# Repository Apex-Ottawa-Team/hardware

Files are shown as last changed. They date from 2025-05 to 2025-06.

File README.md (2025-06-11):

The Ottawa Skybound Logo

# Apex Hardware

## Overview

This repository contains the hardware design files for Ottawa Skybound's weather ballon for [Apex](https://apex.hackclub.com). The repository contains of multiple PCB modules designed in KiCad. The system includes a motherboard, wireless communication module, and various sensor interfaces.

## Boards

LoRa Module: Wireless communication module using LoRa technology. Designed by Adam Turaj

Motherboard: Main control board for the Apex system. Designed by Adam Turaj

Sensor Board: A board containing an IMU and temperature reader. Designed by Joshua Gallinger

Strain ADC: Analog-to-digital converter board for strain measurements. Designed by Adam Turaj

Archive/RF Module: Previous design iteration of the LoRa board. Designed by Adam Turaj

Gas Sensor: Collects data on TVOC concentrations in the air. Designed by Aryan Zafer

Ground RF: Board used to communicate and receive data from the weather balloon. Designed by Aryan Zafer

## Development Requirements

KiCad 9.0 or newer

## License

This project is licensed under the GNU GENERAL PUBLIC LICENSE. The license can be found [here](https://github.com/Apex-Ottawa-Team/hardware/blob/main/LICENSE).

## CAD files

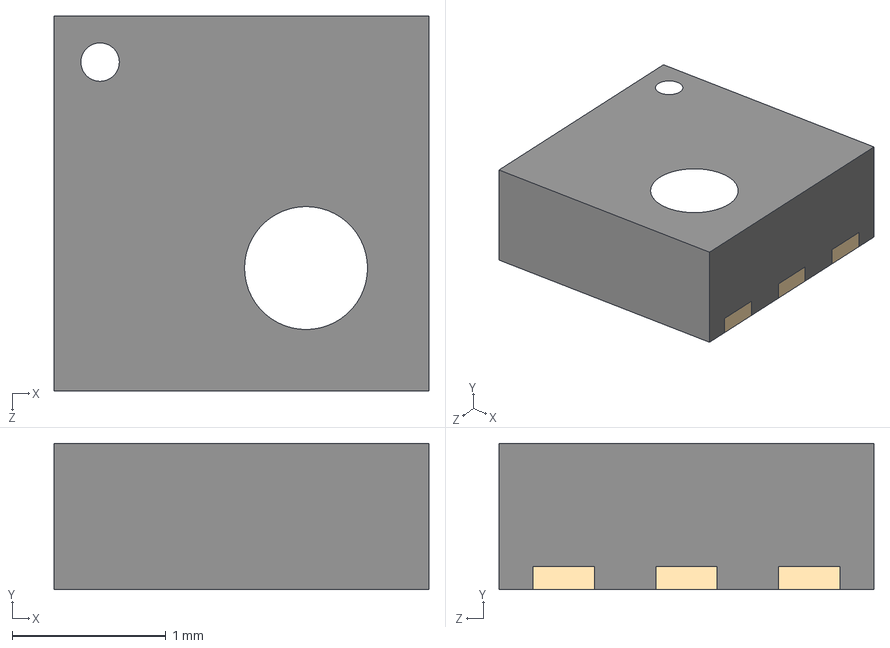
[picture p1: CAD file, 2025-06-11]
Gas Sensor/SGP40-D-R4.step
2.44 x 0.95 x 2.44 mm

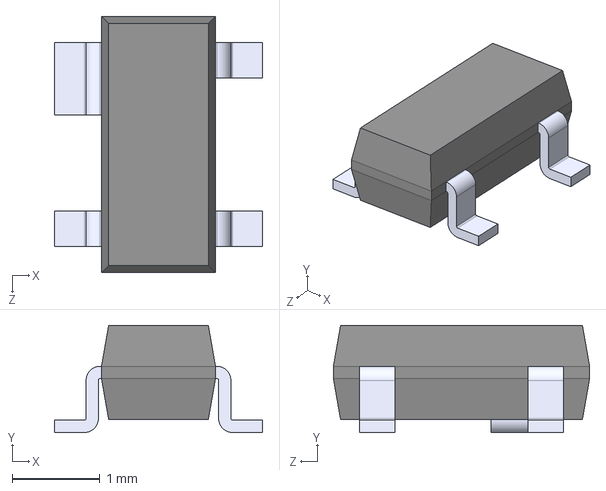
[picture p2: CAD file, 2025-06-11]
Ground RF/3d/SP0503BAHTG.step
2.37 x 1.22 x 2.92 mm

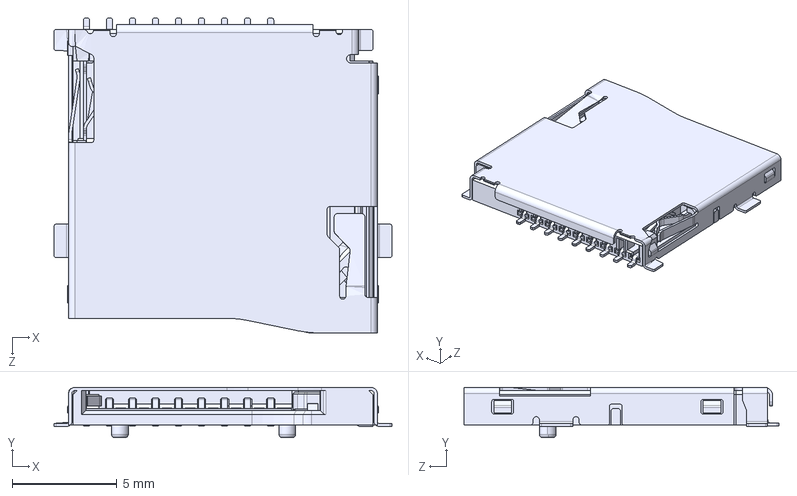
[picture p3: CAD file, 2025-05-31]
Motherboard/STEP/Same_Sky_MSD-1-A.step
16.1 x 2.40 x 15.0 mm

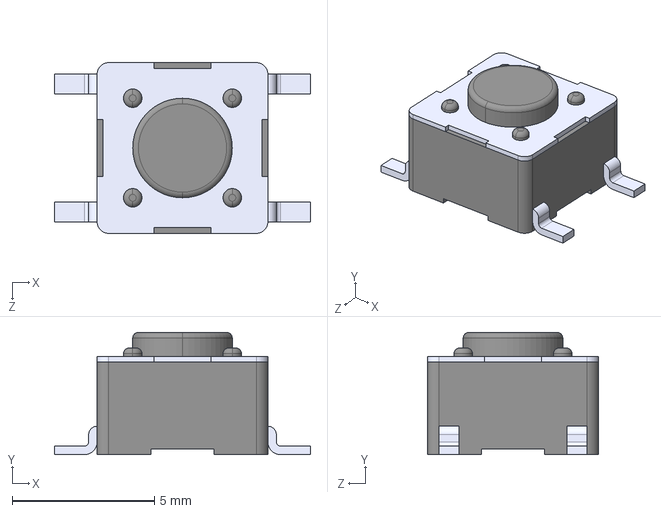
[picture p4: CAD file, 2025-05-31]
Motherboard/STEP/PTS645SK43SMTR92 LFS.STEP
9.00 x 4.30 x 6.00 mm

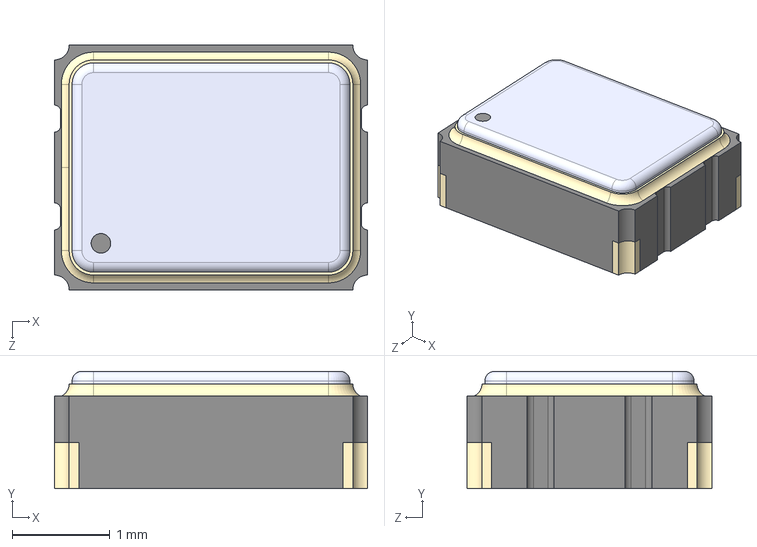
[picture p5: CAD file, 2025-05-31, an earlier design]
Archive/RF Module/Models/TX32-M010S-32.000-X-R.STEP
3.20 x 1.20 x 2.50 mm

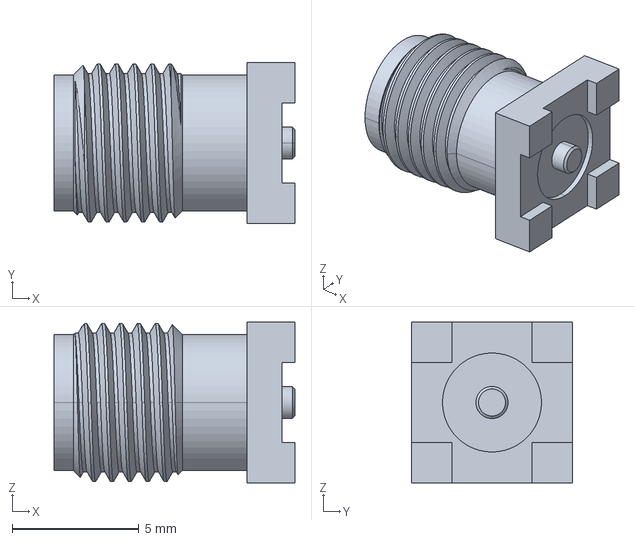
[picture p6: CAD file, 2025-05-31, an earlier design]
Archive/RF Module/Models/732511353.stp
9.53 x 6.35 x 6.35 mm

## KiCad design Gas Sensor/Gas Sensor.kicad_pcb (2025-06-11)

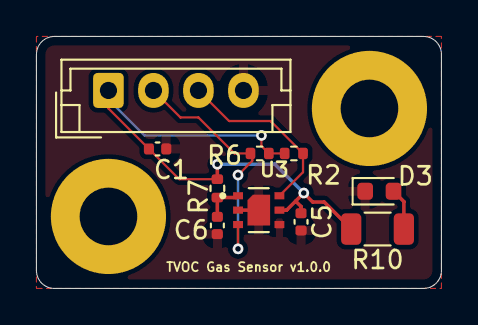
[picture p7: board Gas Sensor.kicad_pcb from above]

Board: 2 copper layers, 22.5 x 14.0 mm, 10 parts (0 on the bottom side), 6 nets.

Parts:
C1: 10uF; C_0402_1005Metric
C5, C6: 0.1uF; C_0402_1005Metric
D3: LED; LED_0603_1608Metric
J1: Conn_Sensors; JST_EH_B4B-EH-A_1x04_P2.50mm_Vertical
R2, R6: 10k; R_0402_1005Metric
R7: 4.7; R_0402_1005Metric
R10: 220; R_1206_3216Metric
U3: SGP40-D-R4; XCDR_SGP40-D-R4

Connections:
+3.3V: C1.1, C5.1, J1.1 (VCC), R2.1, R6.2, R7.2, R10.1, U3.5 (VDDH)
GND: C1.2, C5.2, C6.2, D3.1 (K), J1.4 (GND), U3.2 (VSS), U3.4 (N/A), U3.7 (EXP)
unnamed: D3.2 (A), R10.2
unnamed: C6.1, R7.1, U3.1 (VDD)
SCL: J1.3 (SNS_SCL), R2.2, U3.6 (SCL)
SDA: J1.2 (SNS_SDA), R6.1, U3.3 (SDA)

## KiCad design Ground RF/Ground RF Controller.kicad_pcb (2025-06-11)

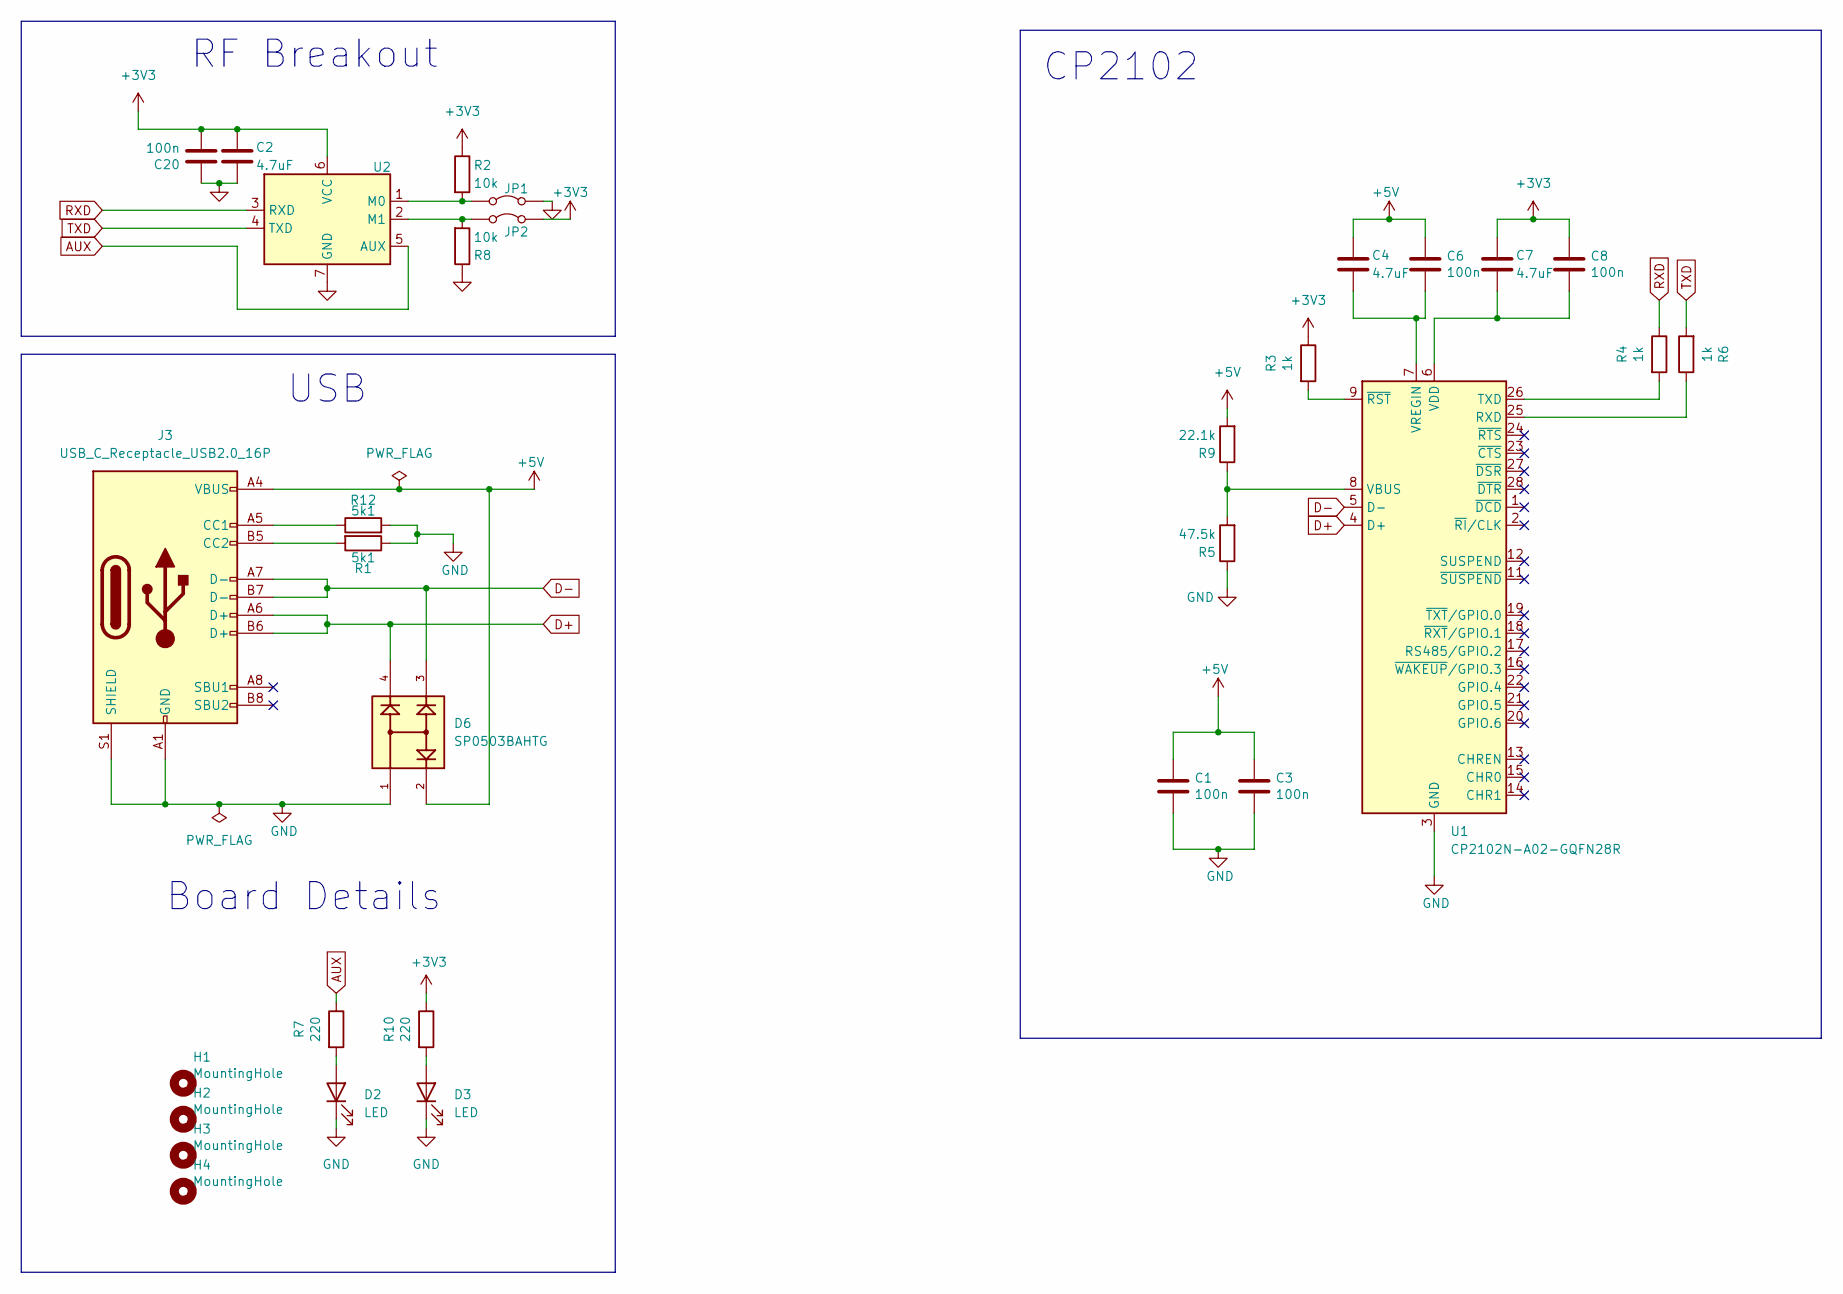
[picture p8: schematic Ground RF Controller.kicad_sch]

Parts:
C1, C3, C6, C8, C20: 100n; C_0402_1005Metric; MPN GRM152R61A104KE19D
C2, C4, C7: 4.7uF; C_0402_1005Metric; MPN GRM155R60J475ME47D
D2, D3: LED; LED_0603_1608Metric; MPN RC0603FR-075K1L
D6: SP0503BAHTG; SOT143; PARTREV N/A
H1, H2, H3, H4: MountingHole; MountingHole_2.7mm_M2.5
J3: USB_C_Receptacle_USB2.0_16P; USB_C_Receptacle_GCT_USB4105-xx-A_16P_TopMnt_Horizontal; MPN USB4105-GF-A-120
JP1, JP2: Jumper_2_Bridged; SolderJumper-2_P1.3mm_Open_RoundedPad1.0x1.5mm
R1, R12: 5k1; R_0603_1608Metric; MPN RC0603FR-075K1L
R2, R8: 10k; R_0402_1005Metric; MPN RC0402JR-0710KL
R3, R4, R6: 1k; R_0805_2012Metric; MPN RC0805JR-071KL
R5: 47.5k; R_0402_1005Metric; MPN CRCW040247K5FKEDC
R7, R10: 220; R_1206_3216Metric; MPN RC1206JR-10220RL
R9: 22.1k; R_0402_1005Metric; MPN CRCW040222K1FKEDC
U1: CP2102N-A02-GQFN28R; QFN-28-1EP_5x5mm_P0.5mm_EP3.35x3.35mm; MPN CP2102N-A02-GQFN28R
U2: EBYTE-E220-900T22D

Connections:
+3V3: C2.1, C7.1, C8.1, C20.2, JP2.2 (B), R2.1, R3.1, R10.1, U2.6 (VCC)
+5V: C1.1, C3.1, C4.1, C6.1, D6.2, J3.A4 (VBUS), J3.A9 (VBUS), J3.B4 (VBUS), J3.B9 (VBUS), R9.2
AUX: R7.1, U2.5 (AUX)
D+: D6.4, J3.A6 (D+), J3.B6 (D+), U1.4 (D+)
D-: D6.3, J3.A7 (D-), J3.B7 (D-), U1.5 (D-)
GND: C1.2, C2.2, C3.2, C20.1, D2.1 (K), D3.1 (K), D6.1, J3.A1 (GND), J3.A12 (GND), J3.B1 (GND), J3.B12 (GND), J3.S1 (SHIELD), JP1.2 (B), R1.1, R5.1, R8.1, R12.2, U1.3 (GND), U1.29 (GND), U2.7 (GND)
unnamed: D2.2 (A), R7.2
unnamed: D3.2 (A), R10.2
unnamed: J3.A5 (CC1), R12.1
unnamed: J3.B5 (CC2), R1.2
unnamed: JP1.1 (A), R2.2, U2.1 (M0)
unnamed: JP2.1 (A), R8.2, U2.2 (M1)
unnamed: R6.1, U1.25 (RXD)
unnamed: R4.2, U1.26 (TXD)
unnamed: R5.2, R9.1, U1.8 (VBUS)
unnamed: C7.2, C8.2, U1.6 (VDD)
unnamed: C4.2, C6.2, U1.7 (VREGIN)
unnamed: R3.2, U1.9 (~RST)
RXD: R4.1, U2.3 (RXD)
TXD: R6.2, U2.4 (TXD)

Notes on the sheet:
USB
CP2102
RF Breakout
Board Details

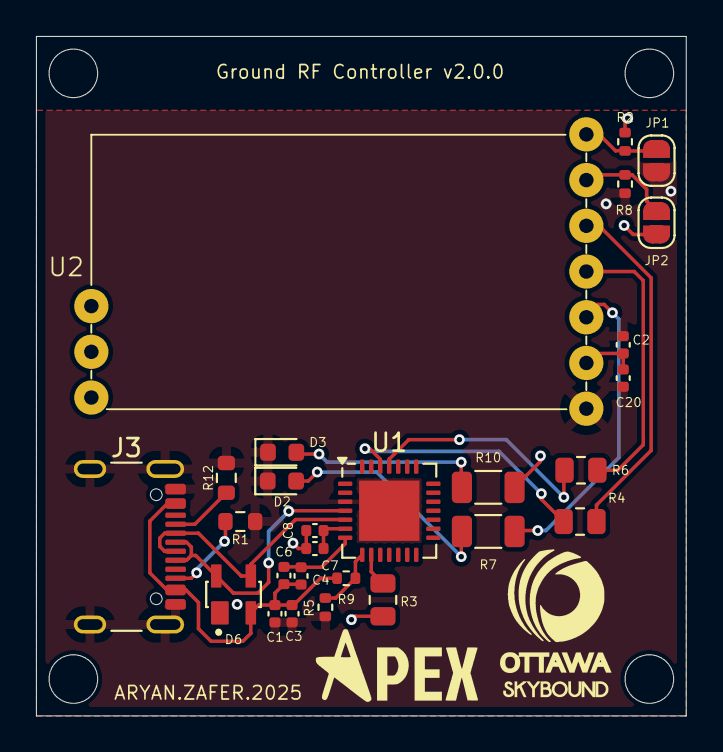
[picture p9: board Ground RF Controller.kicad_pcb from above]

Board: 4 copper layers, 36.1 x 37.8 mm, 31 parts (0 on the bottom side), 20 nets.

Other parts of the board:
H3#2, H3#3, H3#4: MountingHole; MountingHole_2.7mm_M2.5

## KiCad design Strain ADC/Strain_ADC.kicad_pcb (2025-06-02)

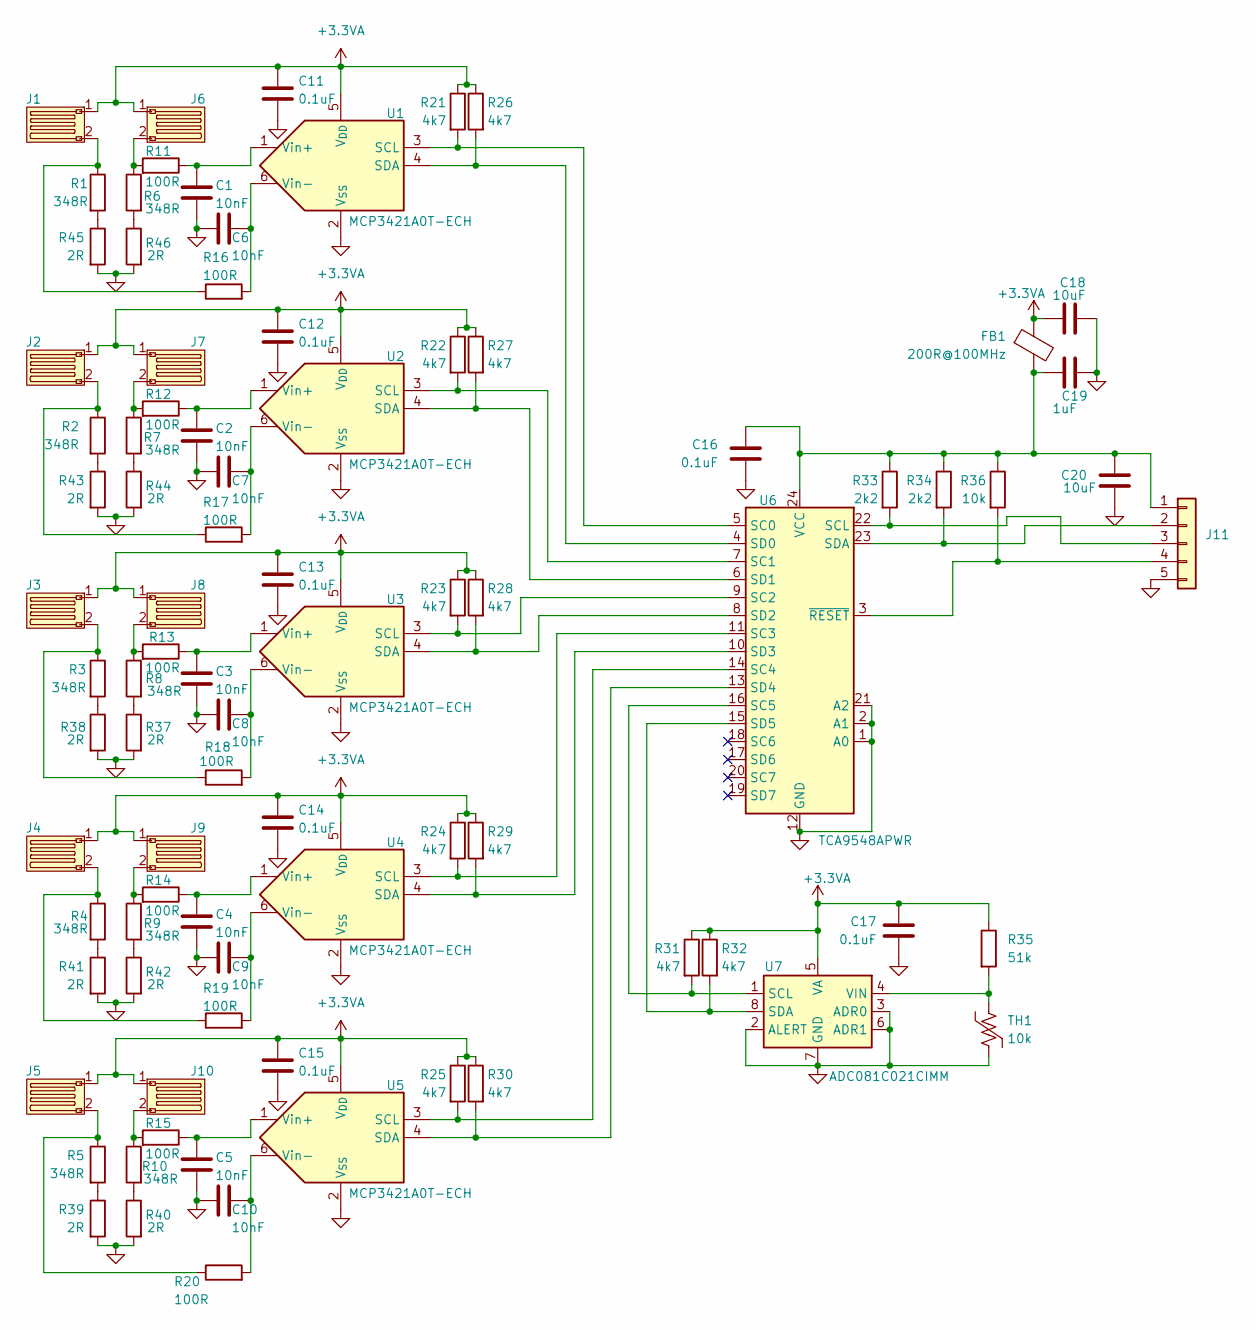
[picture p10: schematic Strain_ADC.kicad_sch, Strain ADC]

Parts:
C1, C2, C3, C4, C5, C6, C7, C8, C9, C10: 10nF; C_0402_1005Metric; Part Number GRM155R71C103KA01D
C11, C12, C13, C14, C15, C16, C17: 0.1uF; C_0402_1005Metric; Part Number CL05B104KP5NNNC
C18, C20: 10uF; C_0402_1005Metric; Part Number CL05A106MQ5NUNC
C19: 1uF; C_0402_1005Metric; Part Number GRM155R70J105KA12D
FB1: 200R@100MHz; L_0805_2012Metric; Part Number BLM21PG221SN1
J1, J2, J3, J4, J5, J6, J7, J8, J9, J10: R_0805_2012Metric
J11: Conn_01x05; JST_XH_B5B-XH-A_1x05_P2.50mm_Vertical; Part Number B5B-XH-A
R1, R2, R3, R4, R5, R6, R7, R8, R9, R10: 348R; R_0402_1005Metric; Part Number ERA-2AEB3480X
R11, R12, R13, R14, R15, R16, R17, R18, R19, R20: 100R; R_0402_1005Metric; Part Number CRCW0402100RFKEDC
R21, R22, R23, R24, R25, R26, R27, R28, R29, R30, R31, R32: 4k7; R_0402_1005Metric; Part Number RC0402FR-074K7L
R33, R34: 2k2; R_0402_1005Metric; Part Number RC0402FR-072K2L
R35: 51k; R_0402_1005Metric; Part Number ERJ-2RKF5102X
R36: 10k; R_0402_1005Metric; Part Number RC0402JR-0710KL
R37, R38, R39, R40, R41, R42, R43, R44, R45, R46: 2R; R_0603_1608Metric; Part Number RT0603BRE072RL
TH1: 10k; R_Axial_DIN0204_L3.6mm_D1.6mm_P2.54mm_Vertical; Part Number MF52A2103J3470
U1, U2, U3, U4, U5: MCP3421A0T-ECH; SOT-23-6; Part Number MCP3421A0T-E/CH
U6: TCA9548APWR; TSSOP-24_4.4x7.8mm_P0.65mm; Part Number TCA9548APWR
U7: ADC081C021CIMM; MSOP-8_3x3mm_P0.65mm; Part Number ADC081C021CIMKX/NOPB

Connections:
+3.3VA: C11.1, C12.1, C13.1, C14.1, C15.1, C17.1, C18.1, FB1.1, J1.1, J2.1, J3.1, J4.1, J5.1, J6.1, J7.1, J8.1, J9.1, J10.1, R21.1, R22.1, R23.1, R24.1, R25.1, R26.1, R27.1, R28.1, R29.1, R30.1, R31.1, R32.1, R35.1, U1.5 (V_{DD}), U2.5 (V_{DD}), U3.5 (V_{DD}), U4.5 (V_{DD}), U5.5 (V_{DD}), U7.5 (VA)
GND: C1.2, C2.2, C3.2, C4.2, C5.2, C6.2, C7.2, C8.2, C9.2, C10.2, C11.2, C12.2, C13.2, C14.2, C15.2, C16.2, C17.2, C18.2, C19.2, C20.1, J11.5, R37.2, R38.2, R39.2, R40.2, R41.2, R42.2, R43.2, R44.2, R45.2, R46.2, TH1.2, U1.2 (V_{SS}), U2.2 (V_{SS}), U3.2 (V_{SS}), U4.2 (V_{SS}), U5.2 (V_{SS}), U6.1 (A0), U6.2 (A1), U6.12 (GND), U6.21 (A2), U7.2 (ALERT), U7.3 (ADR0), U7.6 (ADR1), U7.7 (GND)
unnamed: J1.2, R1.1, R16.1
unnamed: J2.2, R2.1, R17.1
unnamed: J3.2, R3.1, R18.1
unnamed: J4.2, R4.1, R19.1
unnamed: J5.2, R5.1, R20.1
unnamed: J6.2, R6.1, R11.2
unnamed: J7.2, R7.1, R12.2
unnamed: J8.2, R8.1, R13.2
unnamed: J9.2, R9.1, R14.2
unnamed: J10.2, R10.1, R15.2
unnamed: C16.1, C19.1, C20.2, FB1.2, J11.1, R33.1, R34.1, R36.1, U6.24 (VCC)
unnamed: J11.2, R34.2, U6.23 (SDA)
unnamed: J11.3, R33.2, U6.22 (SCL)
unnamed: J11.4, R36.2, U6.3 (~RESET)
unnamed: R1.2, R45.1
unnamed: R2.2, R43.1
unnamed: R3.2, R38.1
unnamed: R4.2, R41.1
unnamed: R10.2, R40.1
unnamed: R8.2, R37.1
unnamed: R5.2, R39.1
unnamed: R9.2, R42.1
unnamed: R7.2, R44.1
unnamed: R6.2, R46.1
unnamed: R21.2, U1.3 (SCL), U6.5 (SC0)
unnamed: R26.2, U1.4 (SDA), U6.4 (SD0)
unnamed: C1.1, R11.1, U1.1 (Vin+)
unnamed: C6.1, R16.2, U1.6 (Vin-)
unnamed: R22.2, U2.3 (SCL), U6.7 (SC1)
unnamed: R27.2, U2.4 (SDA), U6.6 (SD1)
unnamed: C2.1, R12.1, U2.1 (Vin+)
unnamed: C7.1, R17.2, U2.6 (Vin-)
unnamed: R23.2, U3.3 (SCL), U6.9 (SC2)
unnamed: R28.2, U3.4 (SDA), U6.8 (SD2)
unnamed: C3.1, R13.1, U3.1 (Vin+)
unnamed: C8.1, R18.2, U3.6 (Vin-)
unnamed: R24.2, U4.3 (SCL), U6.11 (SC3)
unnamed: R29.2, U4.4 (SDA), U6.10 (SD3)
unnamed: C4.1, R14.1, U4.1 (Vin+)
unnamed: C9.1, R19.2, U4.6 (Vin-)
unnamed: R25.2, U5.3 (SCL), U6.14 (SC4)
unnamed: R30.2, U5.4 (SDA), U6.13 (SD4)
unnamed: C5.1, R15.1, U5.1 (Vin+)
unnamed: C10.1, R20.2, U5.6 (Vin-)
unnamed: R31.2, U6.16 (SC5), U7.1 (SCL)
unnamed: R32.2, U6.15 (SD5), U7.8 (SDA)
unnamed: R35.2, TH1.1, U7.4 (VIN)

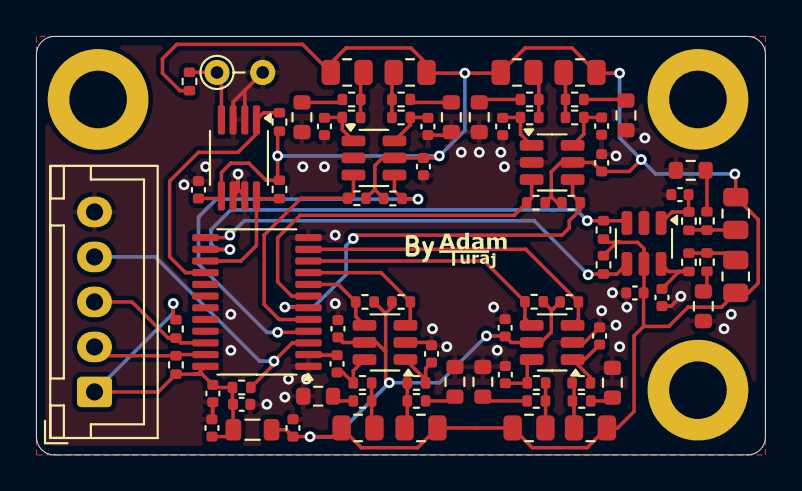
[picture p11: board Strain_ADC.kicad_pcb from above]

Board: 2 copper layers, 40.5 x 23.2 mm, 86 parts (0 on the bottom side), 49 nets.

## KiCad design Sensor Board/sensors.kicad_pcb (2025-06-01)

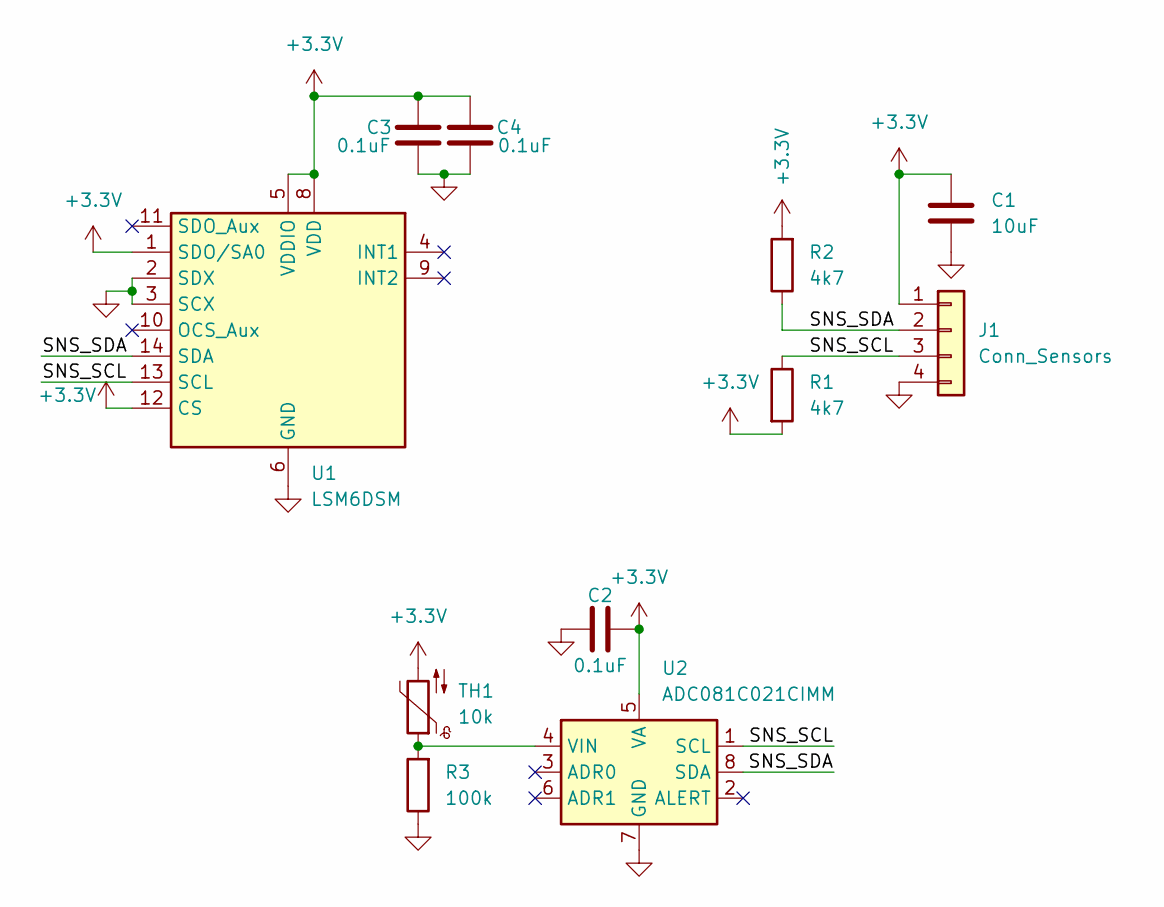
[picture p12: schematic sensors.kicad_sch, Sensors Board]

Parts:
C1: 10uF; C_0402_1005Metric; MPN 0402W106M6R3HI
C2, C3, C4: 0.1uF; C_0402_1005Metric; MPN 0402B104K160HI
J1: Conn_Sensors; JST_EH_B4B-EH-A_1x04_P2.50mm_Vertical; MPN B4B-XH-A
R1, R2: 4k7; R_0402_1005Metric; MPN RC0402JR-074K7L
R3: 100k; R_0402_1005Metric; MPN RC0402JR-07100KL
TH1: 10k; R_0402_1005Metric; MPN NCU15XH103F6SRC
U1: LSM6DSM; LGA-14_3x2.5mm_P0.5mm_LayoutBorder3x4y; MPN LSM6DSVTR
U2: ADC081C021CIMM; MSOP-8_3x3mm_P0.65mm; MPN ADC081C021CIMM/NOPB

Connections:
+3.3V: C1.1, C2.2, C3.1, C4.1, J1.1 (VCC), R1.2, R2.2, TH1.2, U1.1 (SDO/SA0), U1.5 (VDDIO), U1.8 (VDD), U1.12 (CS), U2.5 (VA)
/SNS_SCL: J1.3 (SNS_SCL), R1.1, U1.13 (SCL), U2.1 (SCL)
/SNS_SDA: J1.2 (SNS_SDA), R2.1, U1.14 (SDA), U2.8 (SDA)
GND: C1.2, C2.1, C3.2, C4.2, J1.4 (GND), R3.1, U1.2 (SDX), U1.3 (SCX), U1.6 (GND), U1.7 (GND), U2.7 (GND)
unnamed: R3.2, TH1.1, U2.4 (VIN)

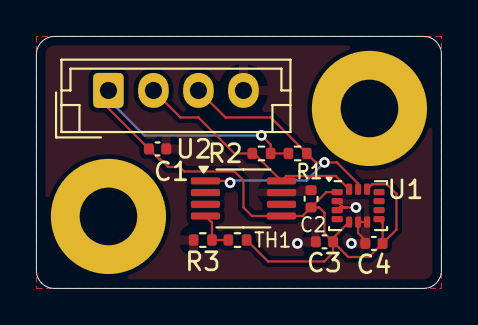
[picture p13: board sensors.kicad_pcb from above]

Board: 2 copper layers, 22.5 x 14.0 mm, 11 parts (0 on the bottom side), 5 nets.

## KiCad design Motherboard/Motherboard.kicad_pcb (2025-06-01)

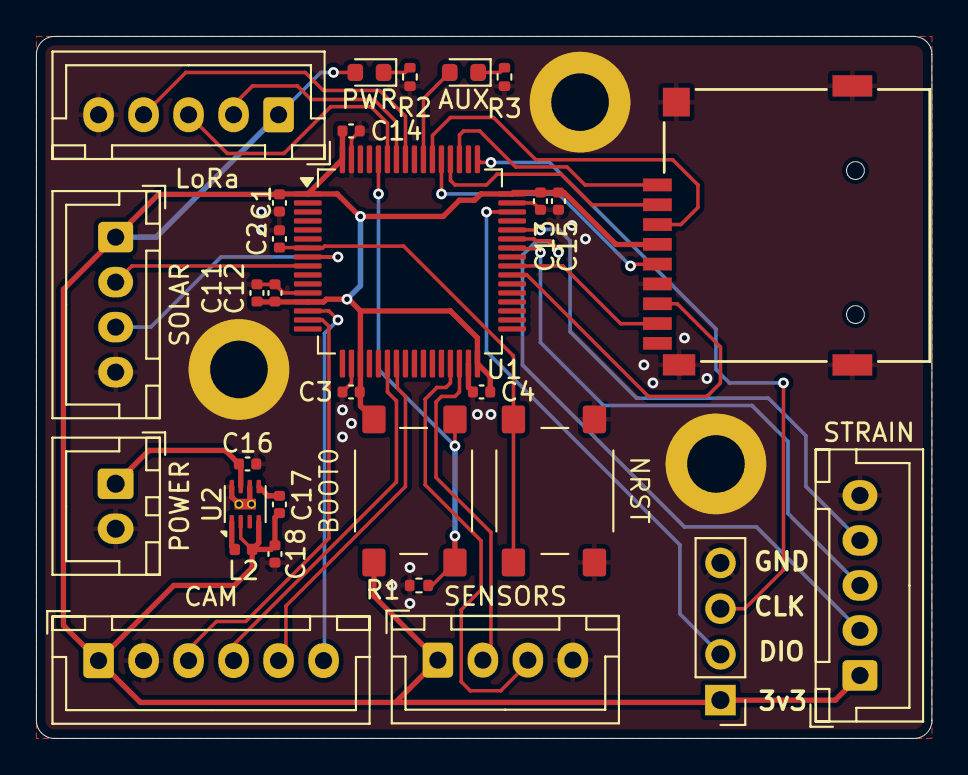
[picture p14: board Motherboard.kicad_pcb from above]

Board: 2 copper layers, 49.8 x 39.0 mm, 30 parts (0 on the bottom side), 32 nets.

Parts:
AUX: GREEN; LED_0603_1608Metric
BOOT0: BOOT0; SW_Push_SMD_6mm
C1, C2, C3, C4, C11, C13, C14: 0.1uF; C_0402_1005Metric
C12: 1uF; C_0402_1005Metric
C15: 10uF; C_0402_1005Metric
C16, C18: 4.7uF; C_0402_1005Metric
C17: 560pF; C_0402_1005Metric
CAM: Conn_Cam; JST_XH_B6B-XH-A_1x06_P2.50mm_Vertical
J3: Micro_SD_Card; CONN9_MSD-1_CUD
J4: Conn_SW; PinHeader_1x04_P2.54mm_Vertical
L2: 1uH; L_0402_1005Metric
LoRa: Conn_RF; JST_XH_B5B-XH-A_1x05_P2.50mm_Vertical
NRST: NRST; SW_Push_SMD_6mm
POWER: Conn_Power; JST_XH_B2B-XH-A_1x02_P2.50mm_Vertical
PWR: RED; LED_0603_1608Metric
R1: 10k; R_0402_1005Metric
R2, R3: 560R; R_0402_1005Metric
SENSORS: Conn_Sensors; JST_XH_B4B-XH-A_1x04_P2.50mm_Vertical
SOLAR: Conn_Solar; JST_XH_B4B-XH-A_1x04_P2.50mm_Vertical
STRAIN: Conn_Strain; JST_XH_B5B-XH-A_1x05_P2.50mm_Vertical
U1: STM32L431RCTx; LQFP-64_10x10mm_P0.5mm
U2: MIC23050-SYML; Micrel_MLF-8-1EP_2x2mm_P0.5mm_EP0.6x1.2mm_ThermalVias

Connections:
+3V3: BOOT0.1, C1.1, C3.1, C4.1, C11.1, C12.1, C13.1, C14.1, C15.1, C17.1, C18.1, CAM.1, J3.4 (VDD), J4.1, L2.1, LoRa.1, PWR.2 (A), SENSORS.1, SOLAR.1, STRAIN.1, U1.1 (VBAT), U1.13 (VDDA), U1.19 (VDD), U1.32 (VDD), U1.48 (VDD), U1.64 (VDD), U2.2 (EN), U2.4 (SNS)
/CAM_CS: CAM.6, U1.14 (PA0)
/CAM_MISO: CAM.4, U1.22 (PA6)
/CAM_MOSI: CAM.5, U1.23 (PA7)
/CAM_SCK: CAM.3, U1.15 (PA1)
/LoRa_INT: LoRa.4, U1.57 (PB5)
/LoRa_RX: LoRa.2, U1.58 (PB6)
/LoRa_TX: LoRa.3, U1.59 (PB7)
/SD_CK: J3.5 (CLK), U1.53 (PC12)
/SD_CMD: J3.3 (CMD), U1.54 (PD2)
/SD_D0: J3.7 (DAT0), U1.39 (PC8)
/SD_D1: J3.8 (DAT1), U1.40 (PC9)
/SD_D2: J3.1 (DAT2), U1.51 (PC10)
/SD_D3: J3.2 (DAT3/CD), U1.52 (PC11)
/SWCLK: J4.3, U1.49 (PA14)
/SWDIO: J4.2, U1.46 (PA13)
/Sensors_SCL: SENSORS.3, U1.29 (PB10)
/Sensors_SDA: SENSORS.2, U1.30 (PB11)
/Solar_SCL: SOLAR.3, U1.8 (PC0)
/Solar_SDA: SOLAR.2, U1.9 (PC1)
/Strain_RST: STRAIN.4, U1.44 (PA11)
/Strain_SCL: STRAIN.3, U1.42 (PA9)
/Strain_SDA: STRAIN.2, U1.43 (PA10)
GND: C1.2, C2.1, C3.2, C4.2, C11.2, C12.2, C13.2, C14.2, C15.2, C16.2, C18.2, CAM.2, J3.6 (VSS), J3.9 (SHIELD), J4.4, LoRa.5, NRST.1, POWER.2, R1.2, R2.2, R3.2, SENSORS.4, SOLAR.4, STRAIN.5, U1.12 (VSSA), U1.18 (VSS), U1.31 (VSS), U1.47 (VSS), U1.63 (VSS), U2.6 (AGND), U2.8 (PGND), U2.9 (EP_GND)
unnamed: PWR.1 (K), R2.1
unnamed: AUX.2 (A), U1.55 (PB3)
unnamed: AUX.1 (K), R3.1
unnamed: C16.1, POWER.1, U2.7 (VIN)
unnamed: C2.2, NRST.2, U1.7 (NRST)
unnamed: BOOT0.2, R1.1, U1.60 (PH3)
unnamed: C17.2, U2.5 (CFF)
unnamed: L2.2, U2.1 (SW)

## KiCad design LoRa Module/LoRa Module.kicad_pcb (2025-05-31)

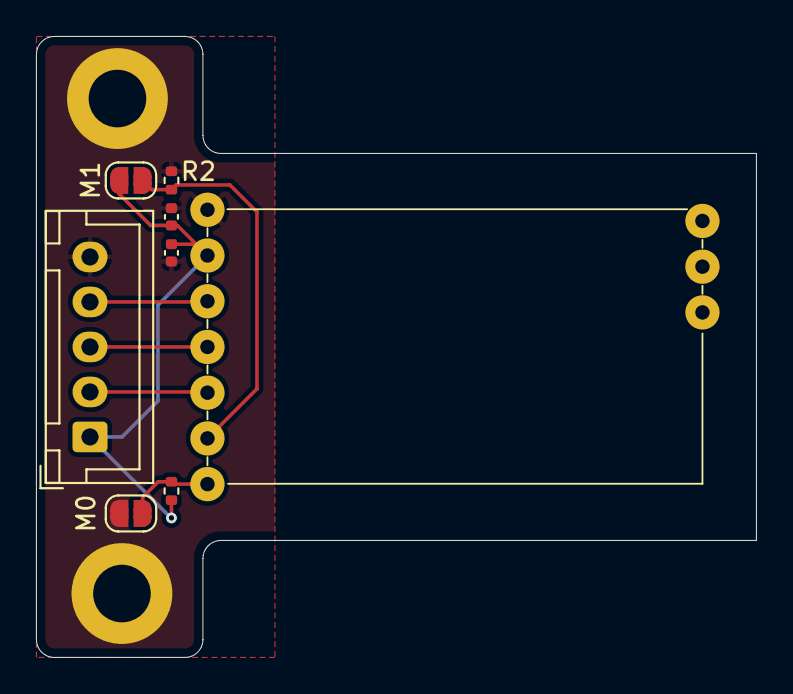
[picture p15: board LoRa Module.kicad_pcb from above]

Board: 2 copper layers, 40.0 x 34.5 mm, 8 parts (0 on the bottom side), 7 nets.

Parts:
C1: 0.1uF; C_0402_1005Metric
C2: 4.7uF; C_0402_1005Metric
J1: Conn_MB; JST_XH_B5B-XH-A_1x05_P2.50mm_Vertical
M0, M1: Jumper_2_Bridged; SolderJumper-2_P1.3mm_Open_RoundedPad1.0x1.5mm
R1, R2: 10k; R_0402_1005Metric
U1: EBYTE-E220-900T22D

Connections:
+3V3: C1.1, C2.1, J1.1, M1.2 (B), R1.1, U1.6 (VCC)
GND: C1.2, C2.2, J1.5, M0.2 (B), R2.1, U1.7 (GND)
unnamed: J1.2, U1.3 (RXD)
unnamed: J1.3, U1.4 (TXD)
unnamed: J1.4, U1.5 (AUX)
unnamed: M0.1 (A), R1.2, U1.1 (M0)
unnamed: M1.1 (A), R2.2, U1.2 (M1)

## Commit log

2025-05-31 Hello World!
    [732511353.stp, LoRa Module.kicad_pcb, LoRa Module.kicad_sch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]
2025-06-01 add MPNs for sensor board components - rts4
    [sensors.kicad_sch]
2025-06-01 Add README and License. Rename folder, minor changes to PCB
    [Motherboard.kicad_pcb, Strain_ADC.kicad_pcb, sensors.kicad_pcb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]
2025-06-02 Add part numbers to remaining PCBs, change part numbers on sensor board, redo strain adc layout
    [LoRa Module.kicad_sch, Motherboard.kicad_sch, Strain_ADC.kicad_pcb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]
2025-06-10 Final Ground RF
    [ottsky-rx.kicad_pcb, ottsky-rx.kicad_sch]
2025-06-11 Starting v2.0.0 schematic
    [Ground RF Controller.kicad_pcb, Ground RF Controller.kicad_sch, SP0503BAHTG.step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]
2025-06-11 v2.0.0 Ground RF finished
    [Ground RF Controller.kicad_pcb, Ground RF Controller.kicad_sch]
2025-06-11 PCB cleanup
    [Ground RF Controller.kicad_pcb]
2025-06-11 Ground RF BOM
2025-06-11 v1.0.0 TVOC Gas Sensor complete.
    [Gas Sensor.kicad_pcb, Gas Sensor.kicad_sch, SGP40-D-R4.step]
2025-06-11 Gas Sensor PCB cleanup
